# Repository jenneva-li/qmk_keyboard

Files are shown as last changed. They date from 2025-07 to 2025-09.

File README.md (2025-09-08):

# Split Keyboard
<p align="center">
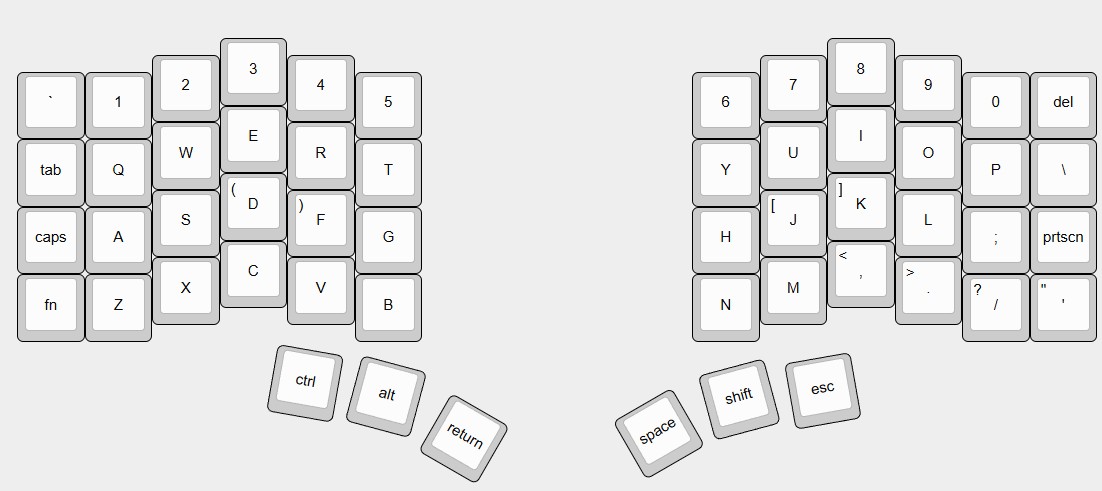
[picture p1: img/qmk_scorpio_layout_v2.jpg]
Keyboard Layout
  
</p>

This is a fully customizable split mechanical keyboard featuring per-key RGB lighting, dual 2.2″ LCD displays, and complete QMK firmware support.

> **Note:** This project is currently under development. Detailed build instructions and documentation will be provided soon.

## Features

- **Ergonomic Split Layout** – Improves typing comfort and reduces strain.  
- **Dual LCD Displays** – Each half includes a 2.2" LCD for customizable graphics and real-time system information.
- **QMK Firmware** – Fully programmable, with support for layers, macros, and custom keymaps.  
- **Per-Key RGB Lighting** – Individually addressable SK6812 Mini LEDs for lighting effects.  
- **Hot-Swappable Switches** – Easily swap switches without soldering.  

## Specifications

- **Microcontroller**: STM32G474CETx
- **Key Layout**: Split layout with additional keys for layers and macros.
- **Display**: 2.2" LCD (320x240 resolution) per half.
- **Lighting**: SK6812 Mini RGB LEDs.
- **Switches**: Kailh Choc Low Profile.

## Build & Assembly

1. Order the PCBs and have them assembled using the provided BOM and pick-and-place files (e.g., via PCBWay).
2. 3D print the keyboard case components and source all necessary hardware, including LCDs, switches, keycaps, and mounting hardware.
3. Assemble all components, ensuring proper alignment of the PCB, switches, and case.
4. Flash the appropriate firmware onto each half of the keyboard. Note that the left and right halves require separate firmware builds.

## Roadmap
> This section outlines the planned features and improvements for the project. It is a work in progress and will be updated as development continues.

- [ ] Finalize PCB design  
- [ ] Publish detailed step-by-step build guide  
- [ ] Write firmware flashing and setup documentation  
- [ ] Upload STL files for 3D-printable case components  
- [ ] Publish demo and assembly videos

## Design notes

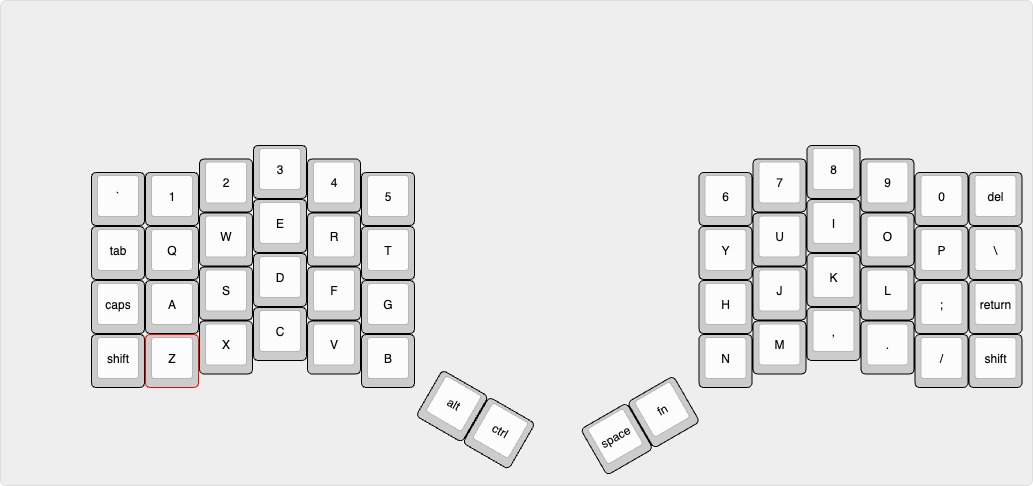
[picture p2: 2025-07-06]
img/qmk_scorpio_layout_v1.jpg

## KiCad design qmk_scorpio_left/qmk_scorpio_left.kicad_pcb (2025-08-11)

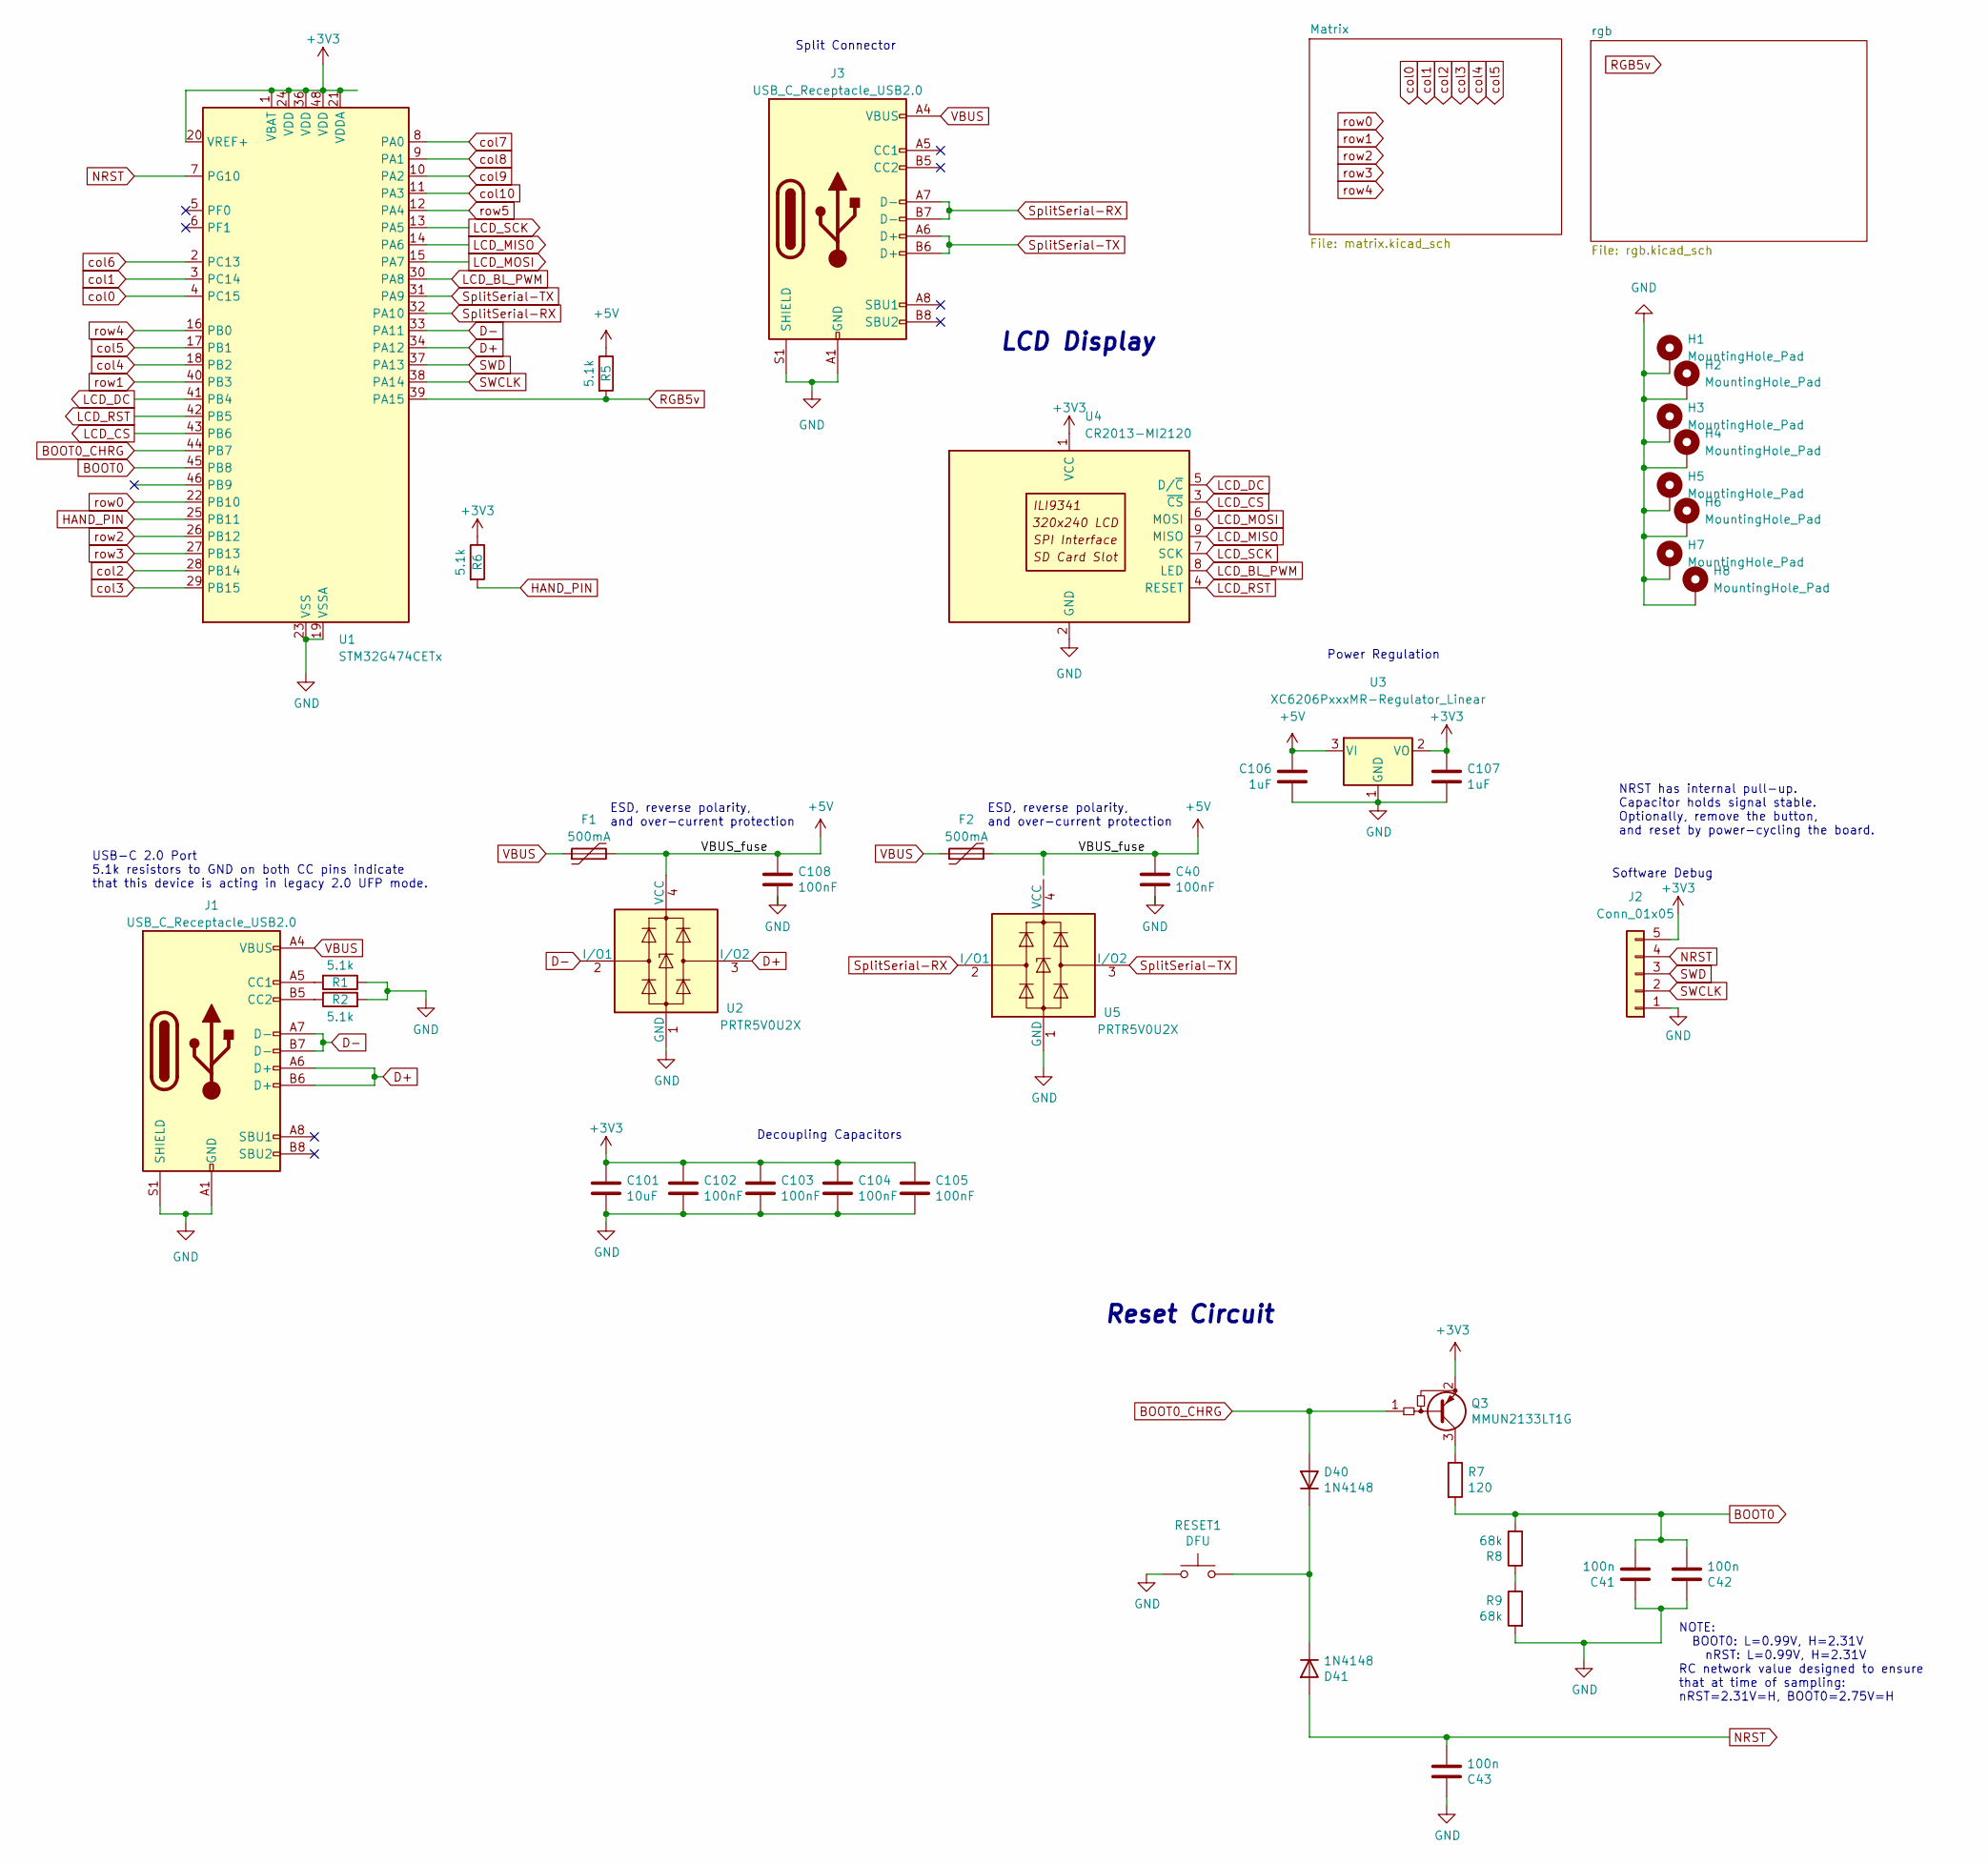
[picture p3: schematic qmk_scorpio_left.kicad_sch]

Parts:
C40, C102, C103, C104, C105, C108: 100nF; C_0402_1005Metric; LCSC C307331
C41, C42, C43: 100n; C_0805_2012Metric
C101: 10uF; C_0603_1608Metric; LCSC C307331
C106, C107: 1uF; C_0402_1005Metric; LCSC C307331
D40, D41: 1N4148; D_SOD-123
F1, F2: 500mA; Fuse_1206_3216Metric; LCSC C135341
H1, H2, H3, H4, H5, H6, H7, H8: MountingHole_Pad; MountingHole_3.2mm_M3_DIN965_Pad
J1, J3: USB_C_Receptacle_USB2.0; USB_C_Receptacle_HRO_TYPE-C-31-M-14; JlcRotOffset 180
J2: Conn_01x05; PinHeader_1x05_P2.54mm_Vertical
Q3: MMUN2133LT1G; SOT-23-3
R1, R2, R5, R6: 5.1k; R_0402_1005Metric
R7: 120; R_0805_2012Metric
R8, R9: 68k; R_0805_2012Metric
RESET1: DFU; SW_SPST_TL3342
U1: STM32G474CETx; LQFP-48_7x7mm_P0.5mm
U2, U5: PRTR5V0U2X; SOT-143; LCSC C2827688
U3: XC6206PxxxMR-Regulator_Linear; SOT-23; LCSC C5446
U4: CR2013-MI2120

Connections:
+3V3: C101.1, C102.1, C103.1, C104.1, C105.1, C107.1, J2.5, Q3.2 (E), R6.1, U1.1 (VBAT), U1.20 (VREF+), U1.21 (VDDA), U1.24 (VDD), U1.36 (VDD), U1.48 (VDD), U3.2 (VO), U4.1 (VCC)
+5V: C40.1, C106.1, C108.1, F1.2, F2.2, R5.1, U2.4 (VCC), U3.3 (VI); also elsewhere on the board
BOOT0: C41.2, C42.2, R7.2, R8.2, U1.45 (PB8)
BOOT0_CHRG: D40.2 (A), Q3.1 (B), U1.44 (PB7)
D+: J1.A6 (D+), J1.B6 (D+), U1.34 (PA12), U2.3 (I/O2)
D-: J1.A7 (D-), J1.B7 (D-), U1.33 (PA11), U2.2 (I/O1)
GND: C40.2, C41.1, C42.1, C43.1, C101.2, C102.2, C103.2, C104.2, C105.2, C106.2, C107.2, C108.2, H1.1, H2.1, H3.1, H4.1, H5.1, H6.1, H7.1, H8.1, J1.A1 (GND), J1.A12 (GND), J1.B1 (GND), J1.B12 (GND), J1.S1 (SHIELD), J2.1, J3.A1 (GND), J3.A12 (GND), J3.B1 (GND), J3.B12 (GND), J3.S1 (SHIELD), R1.1, R2.2, R9.2, RESET1.1, U1.19 (VSSA), U1.23 (VSS), U1.35 (VSS), U1.47 (VSS), U2.1 (GND), U3.1 (GND), U4.2 (GND), U5.1 (GND); also elsewhere on the board
HAND_PIN: R6.2, U1.25 (PB11)
LCD_BL_PWM: U1.30 (PA8), U4.8 (LED)
LCD_CS: U1.43 (PB6), U4.3 (~CS)
LCD_DC: U1.41 (PB4), U4.5 (D/~C)
LCD_MISO: U1.14 (PA6), U4.9 (MISO)
LCD_MOSI: U1.15 (PA7), U4.6 (MOSI)
LCD_RST: U1.42 (PB5), U4.4 (RESET)
LCD_SCK: U1.13 (PA5), U4.7 (SCK)
NRST: C43.2, D41.2 (A), J2.4, U1.7 (PG10)
unnamed: D40.1 (K), D41.1 (K), RESET1.2
unnamed: J1.A5 (CC1), R1.2
unnamed: J1.B5 (CC2), R2.1
unnamed: Q3.3 (C), R7.1
unnamed: R8.1, R9.1
RGB5v: R5.2, U1.39 (PA15); also elsewhere on the board
SWCLK: J2.2, U1.38 (PA14)
SWD: J2.3, U1.37 (PA13)
SplitSerial-RX: J3.A7 (D-), J3.B7 (D-), U1.32 (PA10), U5.2 (I/O1)
SplitSerial-TX: J3.A6 (D+), J3.B6 (D+), U1.31 (PA9), U5.3 (I/O2)
VBUS: F1.1, F2.1, J1.A4 (VBUS), J1.A9 (VBUS), J1.B4 (VBUS), J1.B9 (VBUS), J3.A4 (VBUS), J3.A9 (VBUS), J3.B4 (VBUS), J3.B9 (VBUS)
col0: U1.4 (PC15); also elsewhere on the board
col1: U1.3 (PC14); also elsewhere on the board
col2: U1.28 (PB14); also elsewhere on the board
col3: U1.29 (PB15); also elsewhere on the board
col4: U1.18 (PB2); also elsewhere on the board
col5: U1.17 (PB1); also elsewhere on the board
col6: U1.2 (PC13)
col7: U1.8 (PA0)
col8: U1.9 (PA1)
col9: U1.10 (PA2)
col10: U1.11 (PA3)
row0: U1.22 (PB10); also elsewhere on the board
row1: U1.40 (PB3); also elsewhere on the board
row2: U1.26 (PB12); also elsewhere on the board
row3: U1.27 (PB13); also elsewhere on the board
row4: U1.16 (PB0); also elsewhere on the board
row5: U1.12 (PA4)

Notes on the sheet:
Decoupling Capacitors
NOTE: BOOT0: L=0.99V, H=2.31V nRST: L=0.99V, H=2.31V RC network value designed to ensure that at time of sampling: nRST=2.31V=H, BOOT0=2.75V=H
Power Regulation
Reset Circuit
USB-C 2.0 Port 5.1k resistors to GND on both CC pins indicate that this device is acting in legacy 2.0 UFP mode.
ESD, reverse polarity, and over-current protection
Split Connector
Software Debug
NRST has internal pull-up. Capacitor holds signal stable. Optionally, remove the button, and reset by power-cycling the board.
LCD Display

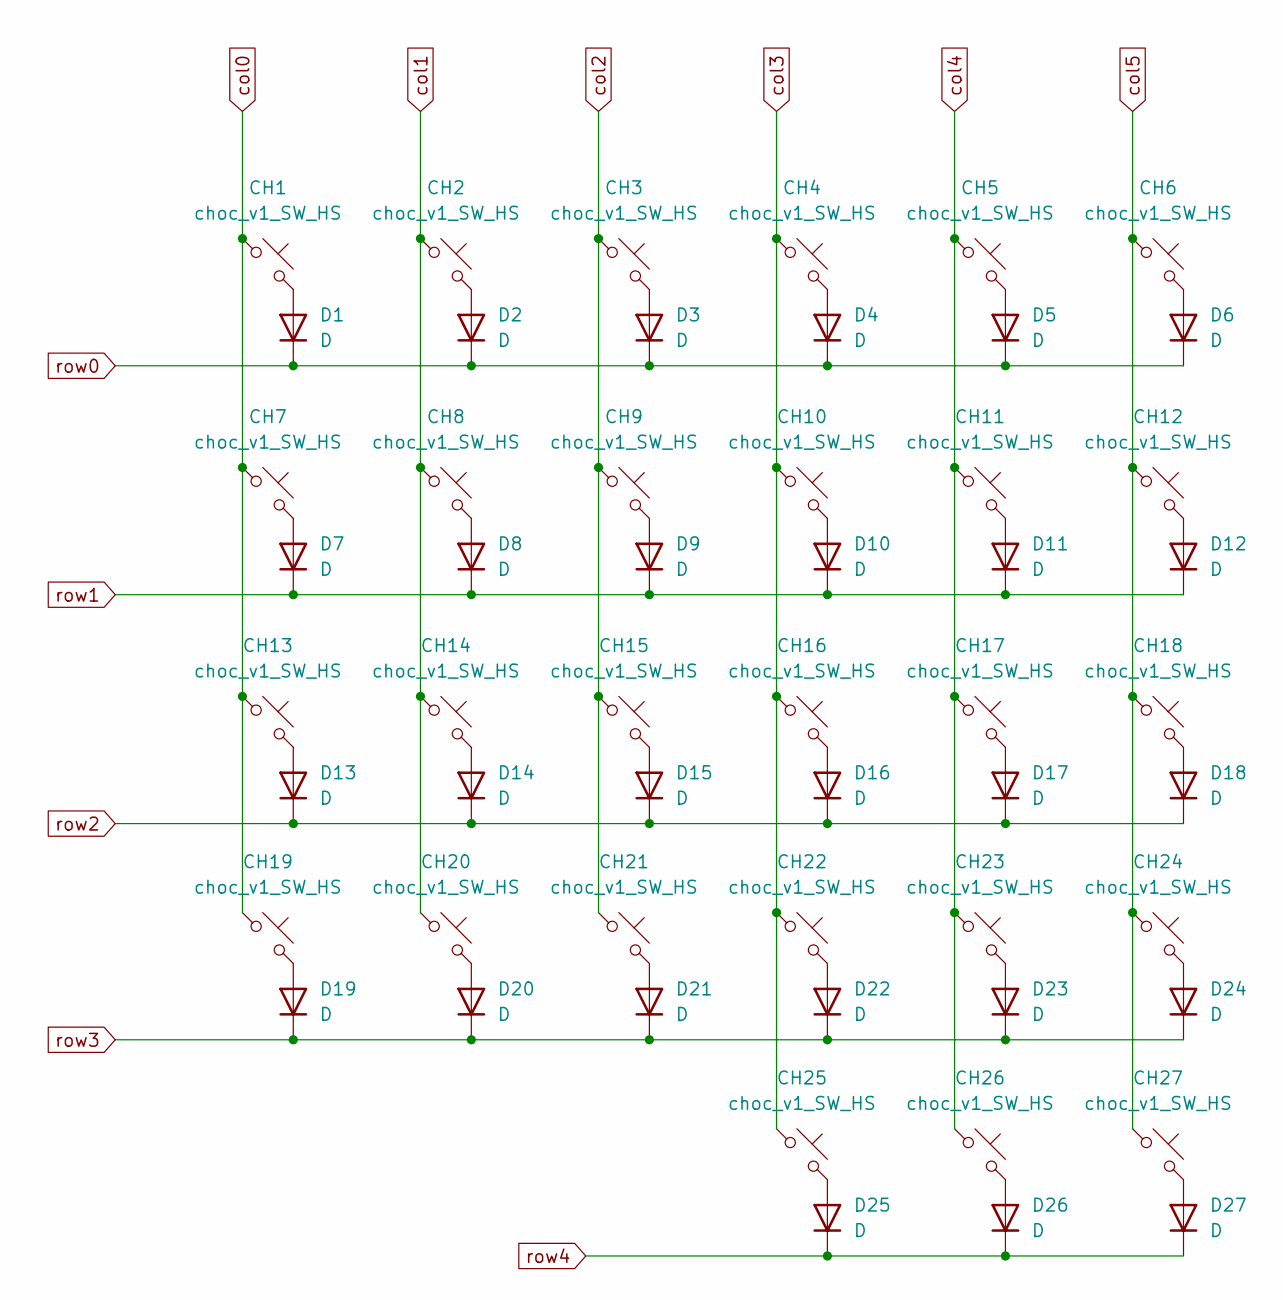
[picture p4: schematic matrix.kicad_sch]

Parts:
CH1, CH3, CH4, CH5, CH6, CH7, CH9, CH10, CH11, CH12, CH13, CH15, CH16, CH17, CH18, CH19, CH21, CH22, CH23, CH24, CH25, CH26, CH27: choc_v1_SW_HS; SW_choc_v1_HS_CPG135001S30_1u
CH2, CH8, CH14, CH20: choc_v1_SW_HS; SW_choc_v1_HS_CPG135001S30_1.5u
D1, D2, D3, D4, D5, D6, D7, D8, D9, D10, D11, D12, D13, D14, D15, D16, D17, D18, D19, D20, D21, D22, D23, D24, D25, D26, D27: D; D_SOD-123

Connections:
unnamed: CH1.2, D1.2 (A)
unnamed: CH2.2, D2.2 (A)
unnamed: CH3.2, D3.2 (A)
unnamed: CH4.2, D4.2 (A)
unnamed: CH5.2, D5.2 (A)
unnamed: CH6.2, D6.2 (A)
unnamed: CH7.2, D7.2 (A)
unnamed: CH8.2, D8.2 (A)
unnamed: CH9.2, D9.2 (A)
unnamed: CH10.2, D10.2 (A)
unnamed: CH11.2, D11.2 (A)
unnamed: CH12.2, D12.2 (A)
unnamed: CH13.2, D13.2 (A)
unnamed: CH14.2, D14.2 (A)
unnamed: CH15.2, D15.2 (A)
unnamed: CH16.2, D16.2 (A)
unnamed: CH17.2, D17.2 (A)
unnamed: CH18.2, D18.2 (A)
unnamed: CH19.2, D19.2 (A)
unnamed: CH20.2, D20.2 (A)
unnamed: CH21.2, D21.2 (A)
unnamed: CH22.2, D22.2 (A)
unnamed: CH23.2, D23.2 (A)
unnamed: CH24.2, D24.2 (A)
unnamed: CH25.2, D25.2 (A)
unnamed: CH26.2, D26.2 (A)
unnamed: CH27.2, D27.2 (A)
col0: CH1.1, CH7.1, CH13.1, CH19.1; also elsewhere on the board
col1: CH2.1, CH8.1, CH14.1, CH20.1; also elsewhere on the board
col2: CH3.1, CH9.1, CH15.1, CH21.1; also elsewhere on the board
col3: CH4.1, CH10.1, CH16.1, CH22.1, CH25.1; also elsewhere on the board
col4: CH5.1, CH11.1, CH17.1, CH23.1, CH26.1; also elsewhere on the board
col5: CH6.1, CH12.1, CH18.1, CH24.1, CH27.1; also elsewhere on the board
row0: D1.1 (K), D2.1 (K), D3.1 (K), D4.1 (K), D5.1 (K), D6.1 (K); also elsewhere on the board
row1: D7.1 (K), D8.1 (K), D9.1 (K), D10.1 (K), D11.1 (K), D12.1 (K); also elsewhere on the board
row2: D13.1 (K), D14.1 (K), D15.1 (K), D16.1 (K), D17.1 (K), D18.1 (K); also elsewhere on the board
row3: D19.1 (K), D20.1 (K), D21.1 (K), D22.1 (K), D23.1 (K), D24.1 (K); also elsewhere on the board
row4: D25.1 (K), D26.1 (K), D27.1 (K); also elsewhere on the board

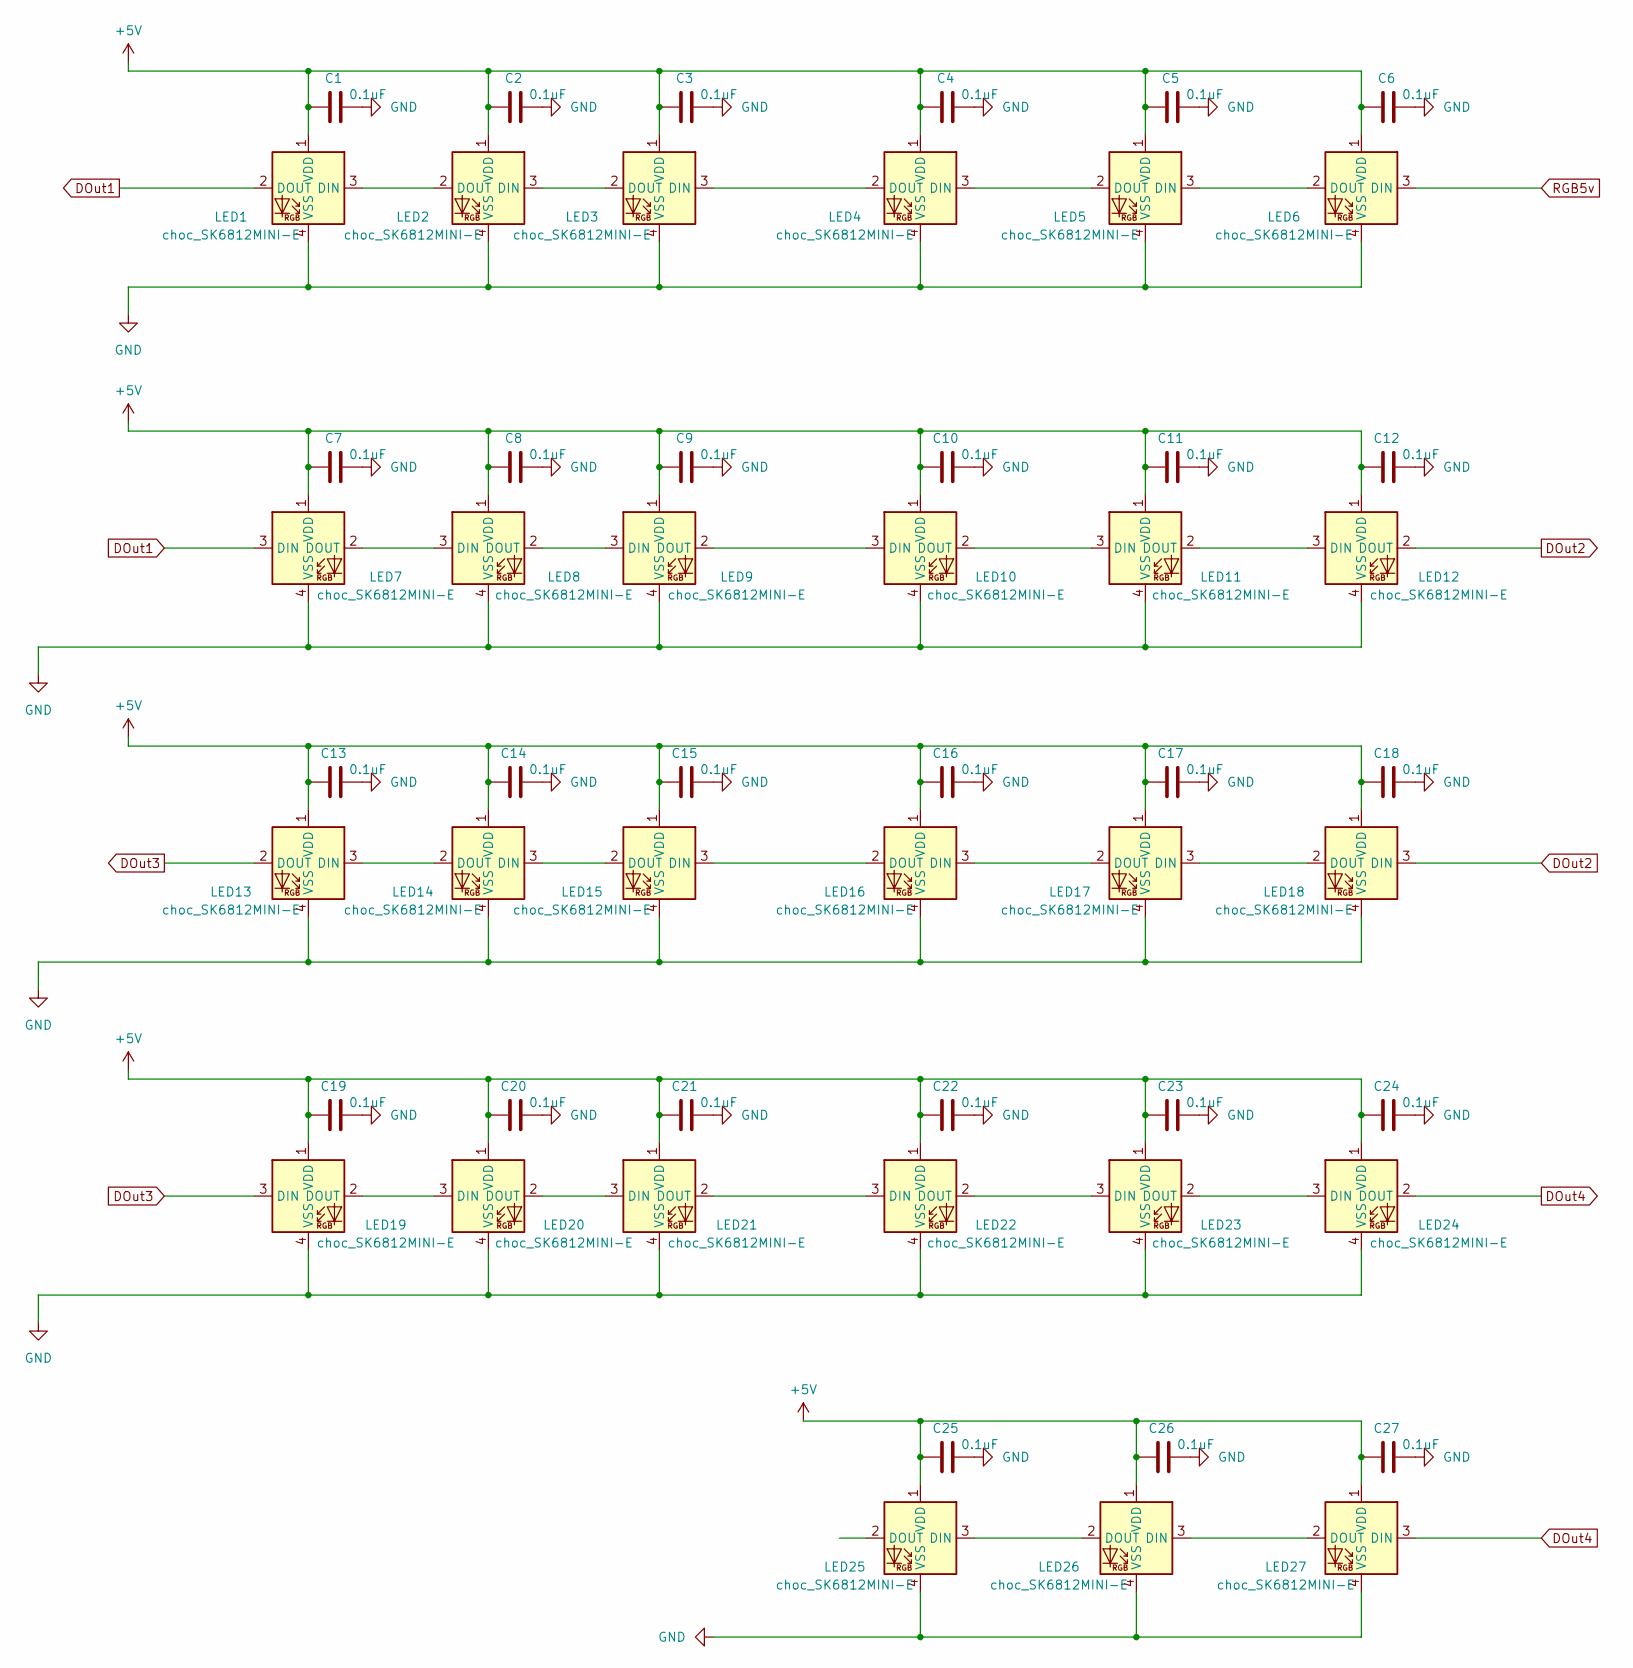
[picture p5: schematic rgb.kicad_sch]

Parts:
C1, C2, C3, C4, C5, C6, C7, C8, C9, C10, C11, C12, C13, C14, C15, C16, C17, C18, C19, C20, C21, C22, C23, C24, C25, C26, C27: 0.1uF; C_0402_1005Metric
LED1, LED2, LED3, LED4, LED5, LED6, LED7, LED8, LED9, LED10, LED11, LED12, LED13, LED14, LED15, LED16, LED17, LED18, LED19, LED20, LED21, LED22, LED23, LED24, LED25, LED26, LED27: choc_SK6812MINI-E; LED_choc_6028R

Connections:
+5V: C1.1, C2.1, C3.1, C4.1, C5.1, C6.1, C7.1, C8.1, C9.1, C10.1, C11.1, C12.1, C13.1, C14.1, C15.1, C16.1, C17.1, C18.1, C19.1, C20.1, C21.1, C22.1, C23.1, C24.1, C25.1, C26.1, C27.1, LED1.1 (VDD), LED2.1 (VDD), LED3.1 (VDD), LED4.1 (VDD), LED5.1 (VDD), LED6.1 (VDD), LED7.1 (VDD), LED8.1 (VDD), LED9.1 (VDD), LED10.1 (VDD), LED11.1 (VDD), LED12.1 (VDD), LED13.1 (VDD), LED14.1 (VDD), LED15.1 (VDD), LED16.1 (VDD), LED17.1 (VDD), LED18.1 (VDD), LED19.1 (VDD), LED20.1 (VDD), LED21.1 (VDD), LED22.1 (VDD), LED23.1 (VDD), LED24.1 (VDD), LED25.1 (VDD), LED26.1 (VDD), LED27.1 (VDD); also elsewhere on the board
DOut1: LED1.2 (DOUT), LED7.3 (DIN)
DOut2: LED12.2 (DOUT), LED18.3 (DIN)
DOut3: LED13.2 (DOUT), LED19.3 (DIN)
DOut4: LED24.2 (DOUT), LED27.3 (DIN)
GND: C1.2, C2.2, C3.2, C4.2, C5.2, C6.2, C7.2, C8.2, C9.2, C10.2, C11.2, C12.2, C13.2, C14.2, C15.2, C16.2, C17.2, C18.2, C19.2, C20.2, C21.2, C22.2, C23.2, C24.2, C25.2, C26.2, C27.2, LED1.4 (VSS), LED2.4 (VSS), LED3.4 (VSS), LED4.4 (VSS), LED5.4 (VSS), LED6.4 (VSS), LED7.4 (VSS), LED8.4 (VSS), LED9.4 (VSS), LED10.4 (VSS), LED11.4 (VSS), LED12.4 (VSS), LED13.4 (VSS), LED14.4 (VSS), LED15.4 (VSS), LED16.4 (VSS), LED17.4 (VSS), LED18.4 (VSS), LED19.4 (VSS), LED20.4 (VSS), LED21.4 (VSS), LED22.4 (VSS), LED23.4 (VSS), LED24.4 (VSS), LED25.4 (VSS), LED26.4 (VSS), LED27.4 (VSS); also elsewhere on the board
unnamed: LED1.3 (DIN), LED2.2 (DOUT)
unnamed: LED2.3 (DIN), LED3.2 (DOUT)
unnamed: LED3.3 (DIN), LED4.2 (DOUT)
unnamed: LED4.3 (DIN), LED5.2 (DOUT)
unnamed: LED5.3 (DIN), LED6.2 (DOUT)
unnamed: LED7.2 (DOUT), LED8.3 (DIN)
unnamed: LED8.2 (DOUT), LED9.3 (DIN)
unnamed: LED9.2 (DOUT), LED10.3 (DIN)
unnamed: LED10.2 (DOUT), LED11.3 (DIN)
unnamed: LED11.2 (DOUT), LED12.3 (DIN)
unnamed: LED13.3 (DIN), LED14.2 (DOUT)
unnamed: LED14.3 (DIN), LED15.2 (DOUT)
unnamed: LED15.3 (DIN), LED16.2 (DOUT)
unnamed: LED16.3 (DIN), LED17.2 (DOUT)
unnamed: LED17.3 (DIN), LED18.2 (DOUT)
unnamed: LED19.2 (DOUT), LED20.3 (DIN)
unnamed: LED20.2 (DOUT), LED21.3 (DIN)
unnamed: LED21.2 (DOUT), LED22.3 (DIN)
unnamed: LED22.2 (DOUT), LED23.3 (DIN)
unnamed: LED23.2 (DOUT), LED24.3 (DIN)
unnamed: LED25.3 (DIN), LED26.2 (DOUT)
unnamed: LED26.3 (DIN), LED27.2 (DOUT)
RGB5v: LED6.3 (DIN); also elsewhere on the board

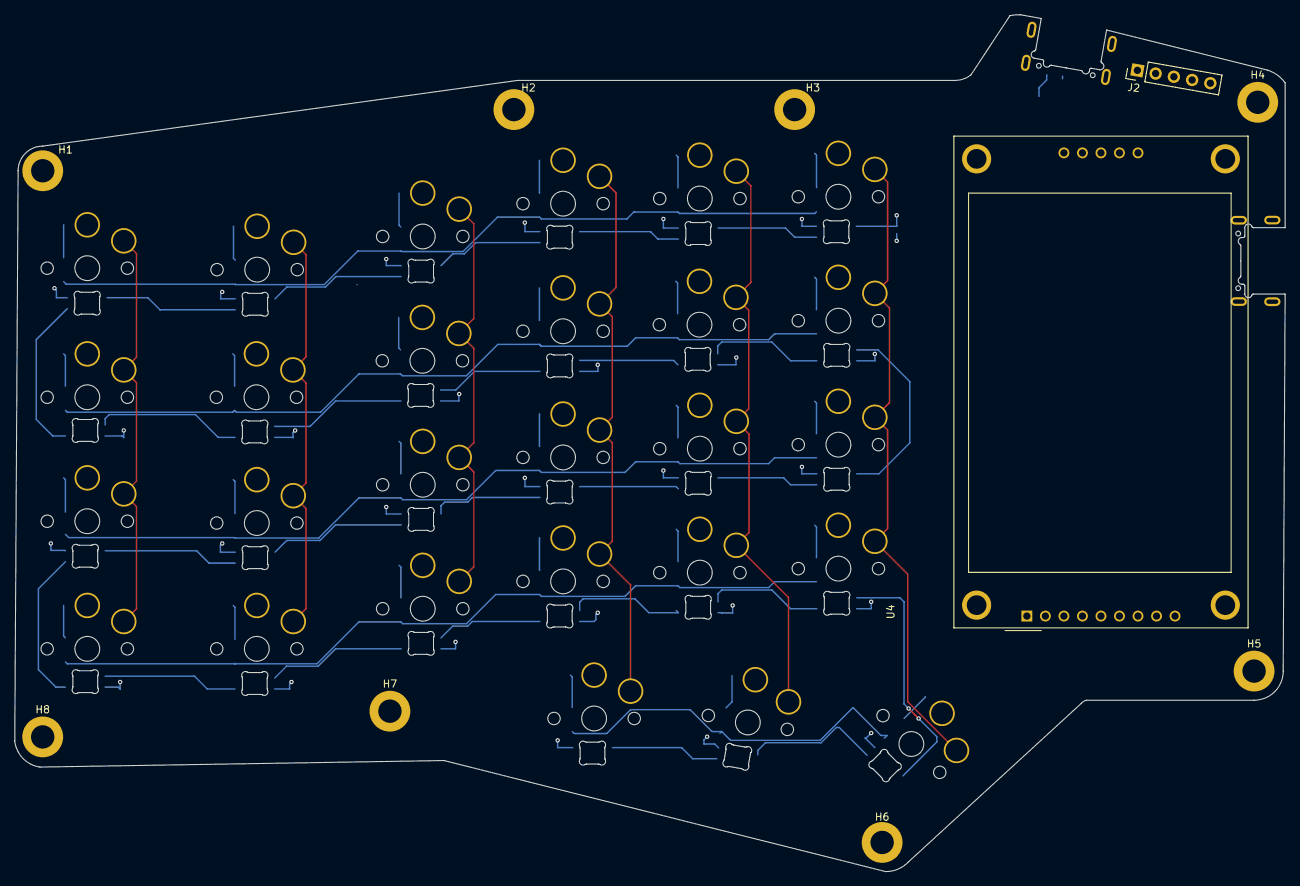
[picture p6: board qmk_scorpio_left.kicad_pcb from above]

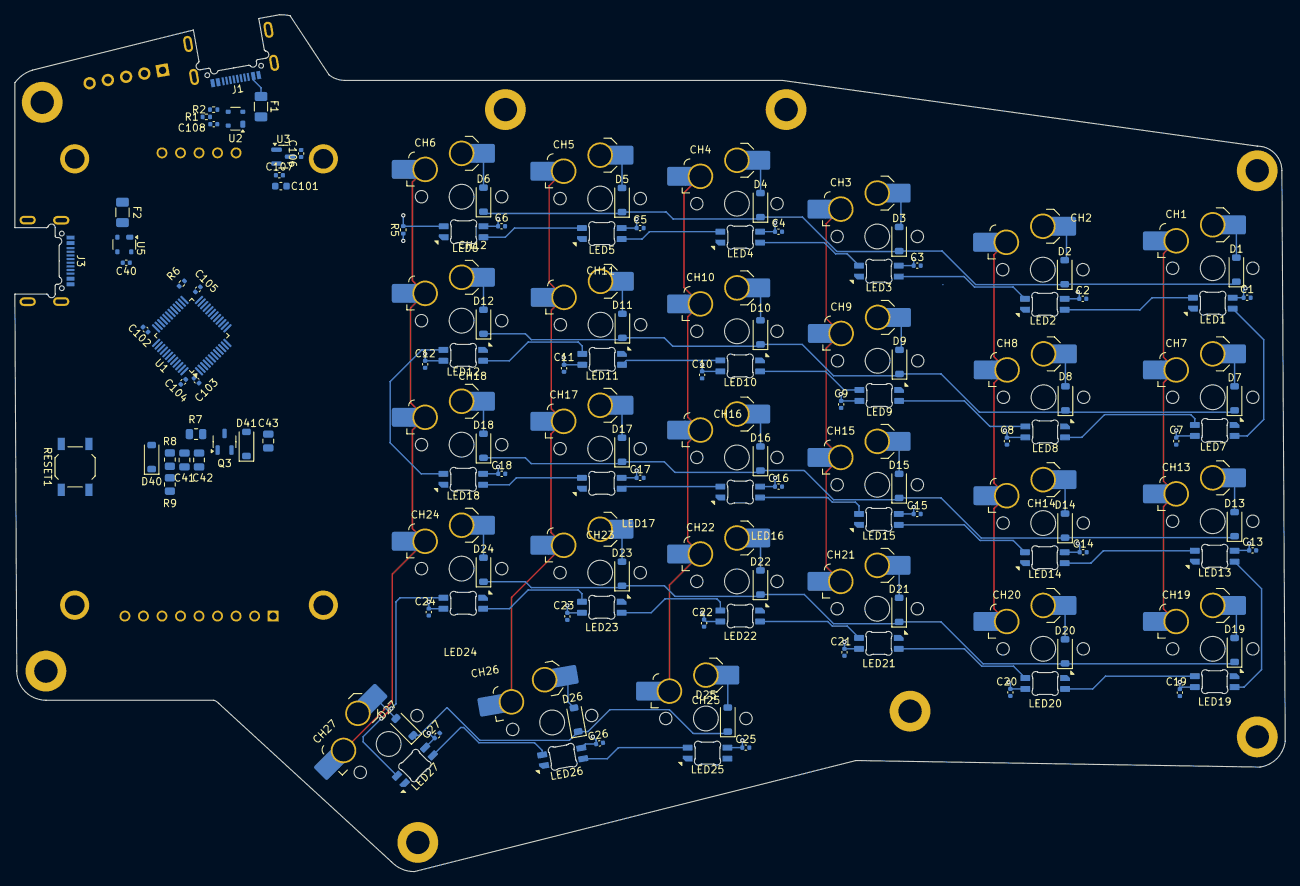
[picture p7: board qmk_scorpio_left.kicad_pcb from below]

Board: 2 copper layers, 174.2 x 117.5 mm, 149 parts (139 on the bottom side), 91 nets.

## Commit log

2025-07-06 add KiCAD project files
    [matrix.kicad_sch, qmk_scorpio_left.kicad_sch, qmk_scorpio_left_old.kicad_pcb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]
2025-07-06 pin corrections and updated rgb
    [qmk_scorpio_left.kicad_sch, rgb.kicad_sch]
2025-08-04 placed all components on board
    [matrix.kicad_sch, qmk_scorpio_left.kicad_pcb, qmk_scorpio_left.kicad_sch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]
2025-08-04 deleted prev board
    [qmk_scorpio_left_old.kicad_pcb]
2025-08-04 fixed annular width drc error
    increased pad diameter from 3.3 mm to 3.5 mm
2025-08-06 fixed col/row connections in matrix schematics
    [matrix.kicad_sch, qmk_scorpio_left.kicad_pcb]
2025-08-08 keys routed
    [qmk_scorpio_left.kicad_pcb]
2025-08-11 placed 5V vias
    [qmk_scorpio_left.kicad_pcb]
